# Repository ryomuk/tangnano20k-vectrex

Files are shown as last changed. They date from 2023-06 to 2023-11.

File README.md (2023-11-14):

# tangnano20k-vectrex
Tang Nano 20K top level module for Dar's Vectrex

This document is written mostly in Japanese. If necessary, please use a translation service such as DeepL (I recommend this) or Google.

## 概要
- Vectrex by Dar (darfpga@aol.fr) http://darfpga.blogspot.fr をTang Nano 20Kで動作させるためのトップレベルモジュール，オシロスコープ用信号出力のためのDAC(MCP4911)用モジュール，および周辺回路の回路図です．
- とりあえず作ってみただけなので，動作は完全ではありませんし，デバッグ用のコード等も入っています．
- [SourceForge DarFPGA](https://sourceforge.net/projects/darfpga/files/Software%20VHDL/vectrex/)にあったDE10-lite用のソースを改変して作りました．
- オリジナルのパッケージのREADME.TXTにあるように，下記のことを理解した上でご使用下さい．
  - Educational use only
  - Do not redistribute synthetized file with roms
  - Do not redistribute roms whatever the form
  - Use at your own risk

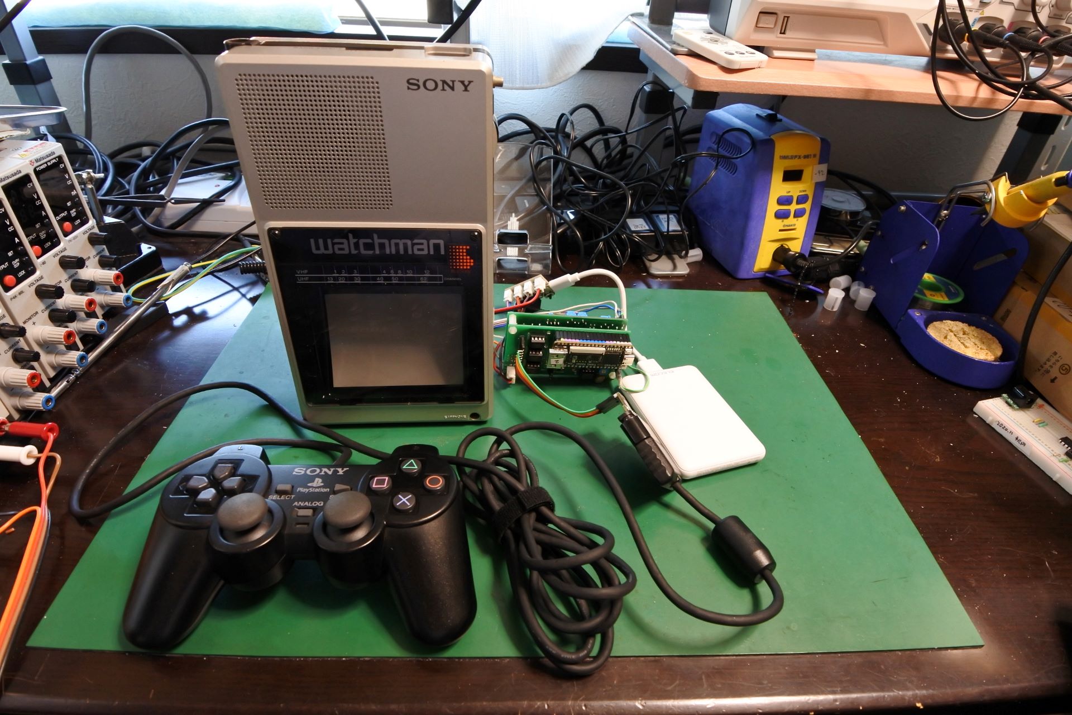
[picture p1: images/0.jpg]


### rev0.3 (まだ改善の余地があり，改版予定ありです．)
- VGA出力用のコードと回路は削除して，XYモニター(オシロスコープ)用の出力専用にしました．
- Sony WatchmanをXYモニタに改造するための回路を追加しました．この回路についての詳細は[https://github.com/ryomuk/XYamp](https://github.com/ryomuk/XYamp)を参照して下さい．

- コントローラーをアナログ対応にしました．TangNano20kゲームキットのコントローラは粗くてスティックの稼働範囲も狭いので，SONY純正のDualShock 2(SCPH-10010)をお薦めします．
- 基板を作ってみました．ブレッドボード版のノイズが改善されるかと思ったのですが改善されませんでした．

FPGA基板
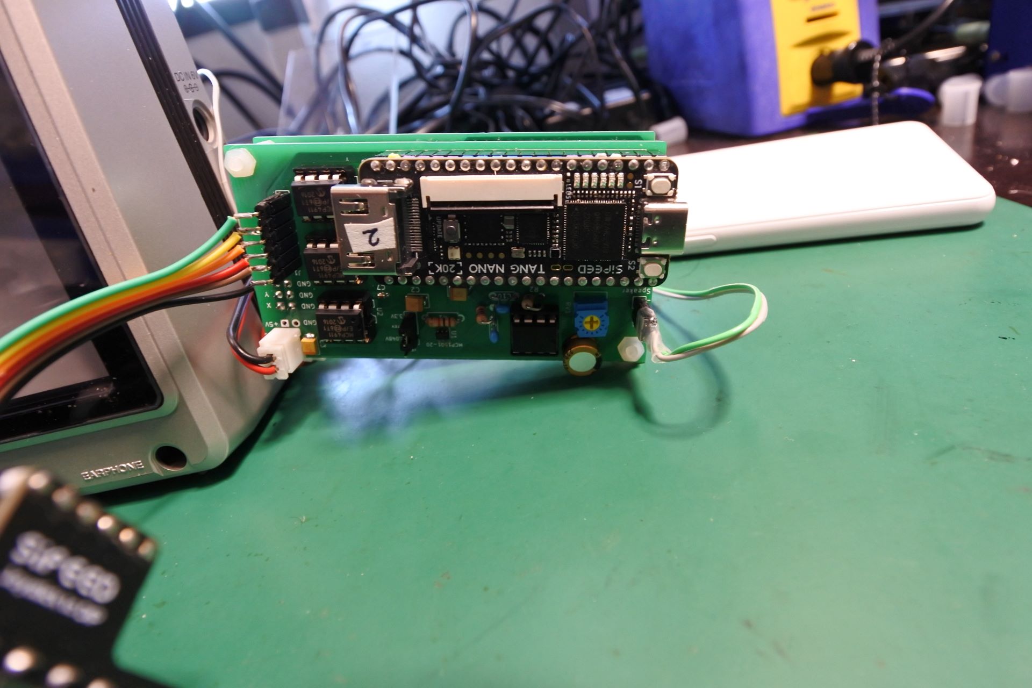
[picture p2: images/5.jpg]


XYアンプ基板
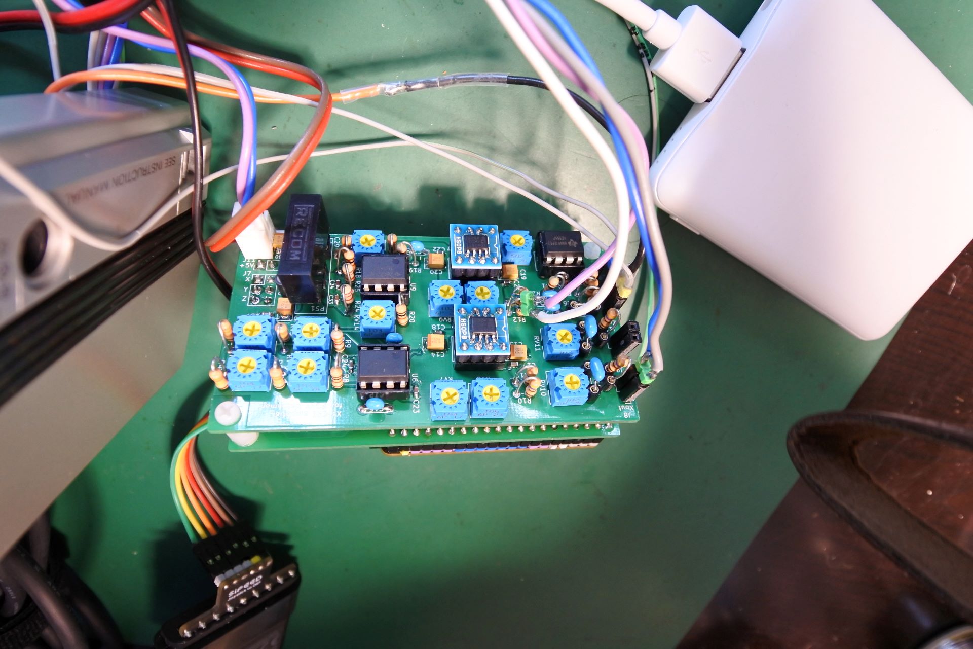
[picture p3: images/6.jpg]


電池ボックスに収納しようとしたけど入らない．
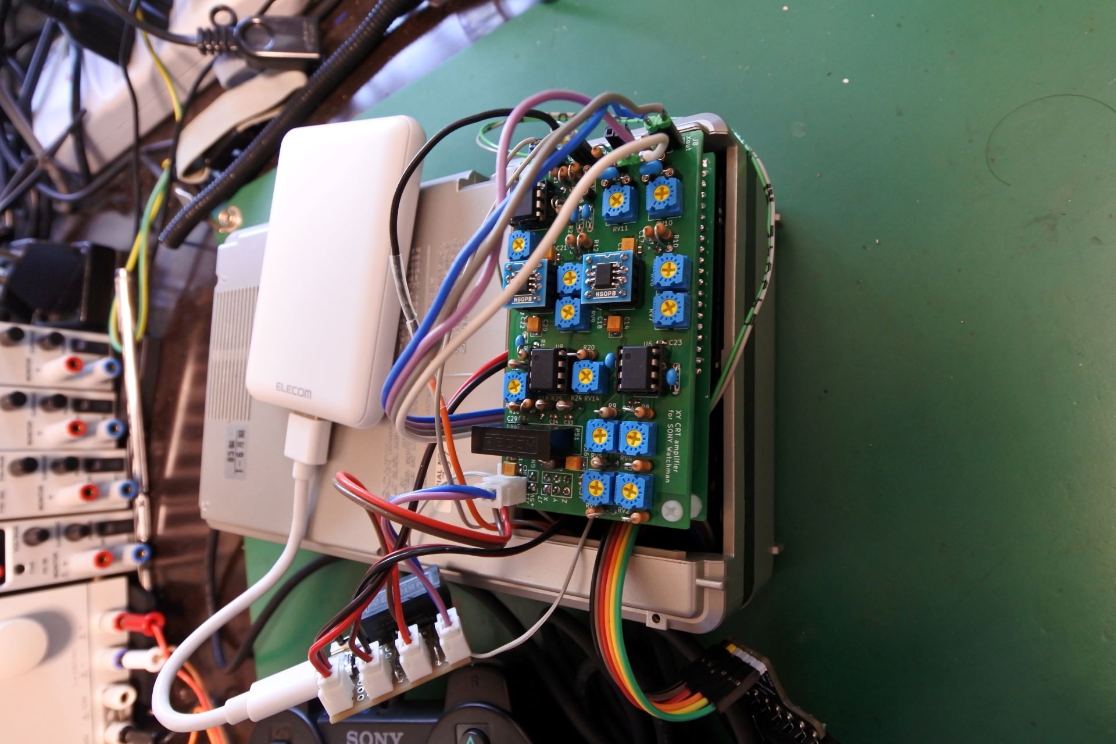
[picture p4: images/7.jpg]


## コンパイル方法

1. [SourceForge DarFPGA](https://sourceforge.net/projects/darfpga/files/Software%20VHDL/vectrex/)にある vhdl_vectrex_rev_0_2_2018_06_12.zip を展開する．
2. 展開してできた下記フォルダを，vectrex_project/src/に中身ごとコピーする．
```
cp -a rtl_dar rtl_jkent rtl_mikej rtl_pace vectrex_project/src/
```
3. ROMデータのvhdlファイルを用意して，romフォルダを作成してそこに置く．
```
mkdir vectrex_project/src/rom
cp vectrex_exec_prom.vhd vectrex_project/src/rom/ (必須)
cp vectrex_scramble_prom.vhd vectrex_project/src/rom/ (ゲームROMデータの例)
```
4. Gowin EDAでプロジェクト vectrex_project.gprj を開いてビルドする．
- "Project->Configuration->Dual-Purpose Pin->Use SSPI as regular IO"をチェックして下さい
- ROMデータのファイルは，プロジェクトに適宜追加・削除して下さい．

## ROMデータについて
- このレポジトリにはROMデータはありません．(romフォルダにあるのは空のテンプレートファイルです．)
- 必要なROMデータは何らかの方法で入手して，オリジナルのパッケージに含まれるREADME.TXTに従ってvhdlファイルを作成して下さい．
- データをVHDLに変換するスクリプトrom/rom2vhd.pl を使ってもいいかも．
- romの名前，サイズに応じて，rtl_dar/vectrex.vhdを適宜修正して下さい．

## その他
- このプロジェクトはあくまでFPGAを使う練習用の試みなので，バグ等があってもメンテナンスをする予定はありません．

# 動画
動作している様子です．

(https://www.youtube.com/watch?v=2sRUTAbVEdg)

## その他の画像
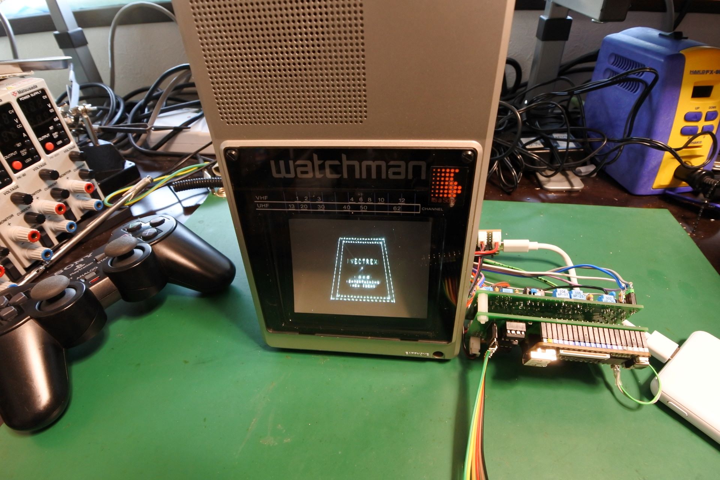
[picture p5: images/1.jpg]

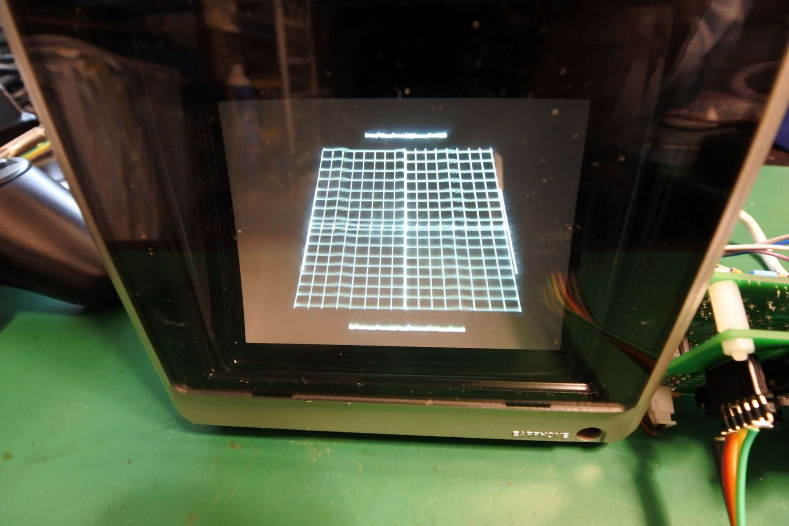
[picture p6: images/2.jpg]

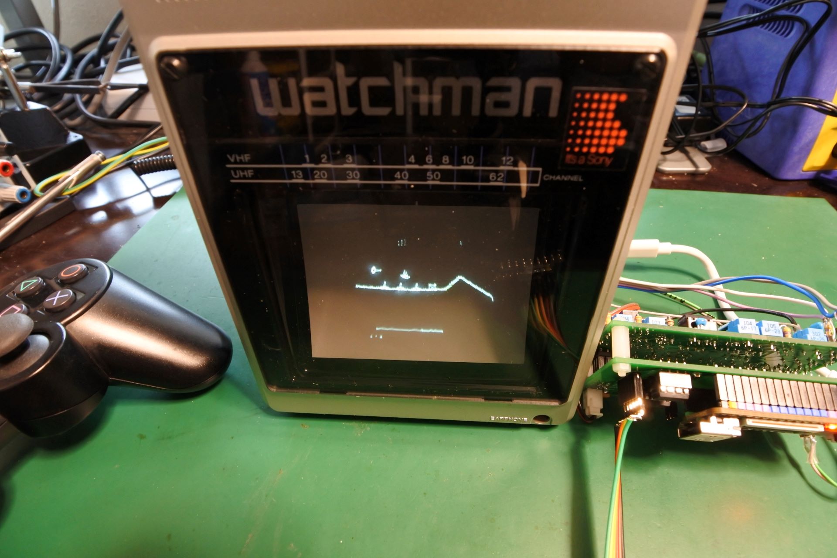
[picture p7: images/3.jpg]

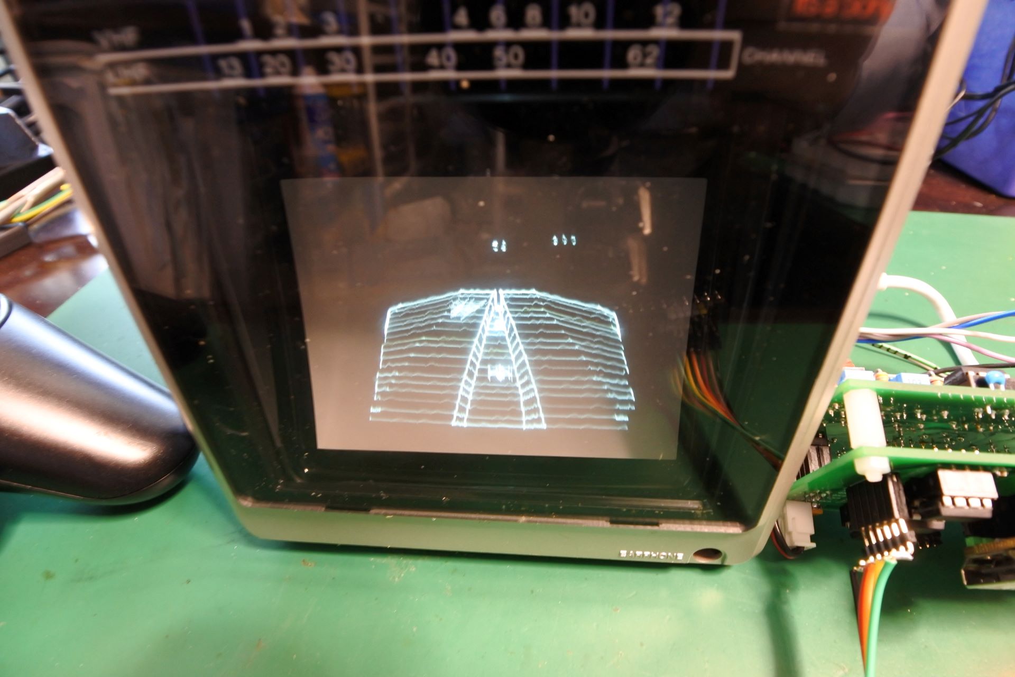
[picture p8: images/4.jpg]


## 更新履歴
- 2023/6/13: 初版公開
- 2023/6/13: 回路図にLPFが抜けていたので追加
- 2023/11/14: rev0.3公開．初版はold/rev0.1に移動．

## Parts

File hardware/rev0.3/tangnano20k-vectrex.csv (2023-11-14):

# | Reference | Qty | Value | Footprint | DNP
1 | C1, C2, C3, C13, C14, C19, C20, C30, C36 | 9 | 22u | 000_MyFootprint:CP_EIA-3528-15_AVX-H_Pad1.50x2.35mm_HandSolder
2 | C4, C5, C6, C7, C8, C9, C17, C18, C21, C22, C23, C24, C31, C37 | 14 | 0.1u | 000_MyFootprint:C_0603_1608Metric_Pad1.08x0.95mm_HandSolder
3 | C10, C27 | 2 | 0.01u | 000_MyFootprint:C_Disc_D4.3mm_W1.9mm_P5.00mm
4 | C11 | 1 | 0.047uF | 000_MyFootprint:C_Disc_D4.3mm_W1.9mm_P5.00mm
5 | C12 | 1 | 220u | 000_MyFootprint:CP_Radial_D4.0mm_P1.50mm
6 | C15, C16, C28 | 3 | 0.1u | 000_MyFootprint:C_Disc_D4.3mm_W1.9mm_P5.00mm
7 | C25, C26 | 2 | 1u | 000_MyFootprint:C_Disc_D4.7mm_W2.5mm_P5.00mm
8 | C29 | 1 | 2.2u | 000_MyFootprint:C_0603_1608Metric_Pad1.08x0.95mm_HandSolder
9 | C32 | 1 | 4700p | 000_MyFootprint:C_Disc_D4.3mm_W1.9mm_P5.00mm
10 | C33, C34 | 2 | 1u | 000_MyFootprint:C_0603_1608Metric_Pad1.08x0.95mm_HandSolder
11 | C35 | 1 | 0.068u | 000_MyFootprint:C_Disc_D4.3mm_W1.9mm_P5.00mm
12 | D1 | 1 | 1N4148 | 000_MyFootprint:D_DO-35_SOD27_P2.54mm_Vertical_AnodeUp
13 | FB1 | 1 | FerriteBead | 000_MyFootprint:R_Axial_DIN0207_L6.3mm_D2.5mm_P2.54mm_Vertical
14 | H1, H2, H3, H4 | 4 | MountingHole | 000_MyFootprint:MountingHole_3mm
15 | J1 | 1 | Joystick | 000_MyFootprint:PinSocket_1x06_P2.54mm_Vertical
16 | J2, J3 | 2 | TangNano20K | 000_MyFootprint:PinSocket_1x20_P2.54mm_Vertical
17 | J4, J11, J12 | 3 | 5V | 000_MyFootprint:PinHeader_1x02_P2.54mm_Vertical
18 | J5 | 1 | Vref | 000_MyFootprint:PinHeader_1x03_P2.54mm_Vertical
19 | J6, J7 | 2 | Conn_02x03_Odd_Even | 000_MyFootprint:PinHeader_2x03_P2.54mm_Vertical
20 | J8 | 1 | Xout | 000_MyFootprint:PinHeader_1x02_P2.54mm_Vertical
21 | J9 | 1 | Yout | 000_MyFootprint:PinHeader_1x02_P2.54mm_Vertical
22 | J10 | 1 | -5V | 000_MyFootprint:PinHeader_1x02_P2.54mm_Vertical
23 | J13 | 1 | flyback | 000_MyFootprint:PinHeader_1x02_P2.54mm_Vertical
24 | J14 | 1 | Zout | 000_MyFootprint:PinHeader_1x02_P2.54mm_Vertical
25 | LS1 | 1 | Speaker | 000_MyFootprint:PinHeader_1x02_P2.54mm_Vertical
26 | PS1 | 1 | MAU109 | 000_MyFootprint:SIP-6_without_3pin_for_DCDC_MAU
27 | R1 | 1 | 1k | 000_MyFootprint:R_Axial_DIN0207_L6.3mm_D2.5mm_P7.62mm_Horizontal
28 | R2, R9, R21 | 3 | 3.3k | 000_MyFootprint:R_Axial_DIN0207_L6.3mm_D2.5mm_P2.54mm_Vertical
29 | R3 | 1 | 10 | 000_MyFootprint:R_Axial_DIN0207_L6.3mm_D2.5mm_P2.54mm_Vertical
30 | R4, R5, R6, R7, R16, R17 | 6 | 330k | 000_MyFootprint:R_Axial_DIN0207_L6.3mm_D2.5mm_P2.54mm_Vertical
31 | R8, R18, R20, R23, R26 | 5 | 1k | 000_MyFootprint:R_Axial_DIN0207_L6.3mm_D2.5mm_P2.54mm_Vertical
32 | R10, R11, R12, R13, R14, R15 | 6 | 4.7 | 000_MyFootprint:R_Axial_DIN0207_L6.3mm_D2.5mm_P2.54mm_Vertical
33 | R19, R22 | 2 | 10k | 000_MyFootprint:R_Axial_DIN0207_L6.3mm_D2.5mm_P2.54mm_Vertical
34 | R24, R25 | 2 | 2.2k | 000_MyFootprint:R_Axial_DIN0207_L6.3mm_D2.5mm_P2.54mm_Vertical
35 | RV1, RV4, RV5, RV14 | 4 | 10k | 000_MyFootprint:Potentiometer_TOCOS_GF063
36 | RV2, RV3, RV7, RV12 | 4 | 100k | 000_MyFootprint:Potentiometer_TOCOS_GF063
37 | RV6, RV8 | 2 | 1M | 000_MyFootprint:Potentiometer_TOCOS_GF063
38 | RV9 | 1 | 1k | 000_MyFootprint:Potentiometer_TOCOS_GF063
39 | RV10, RV11 | 2 | 3k | 000_MyFootprint:Potentiometer_TOCOS_GF063
40 | RV13 | 1 | 5k | 000_MyFootprint:Potentiometer_TOCOS_GF063
41 | U1 | 1 | MCP1501-20 | Package_TO_SOT_SMD:SOT-23-6
42 | U2, U3, U4 | 3 | MCP4911 | 000_MyFootprint:DIP-8_W7.62mm
43 | U5 | 1 | LM386 | 000_MyFootprint:DIP-8_W7.62mm
44 | U6, U9 | 2 | TL072 | 000_MyFootprint:DIP-8_W7.62mm
45 | U7, U8 | 2 | AD8397 | 000_MyFootprint:DIP-8_W7.62mm_with_SOP8_with_heatpadhole
46 | U10 | 1 | NE555 | 000_MyFootprint:DIP-8_W7.62mm

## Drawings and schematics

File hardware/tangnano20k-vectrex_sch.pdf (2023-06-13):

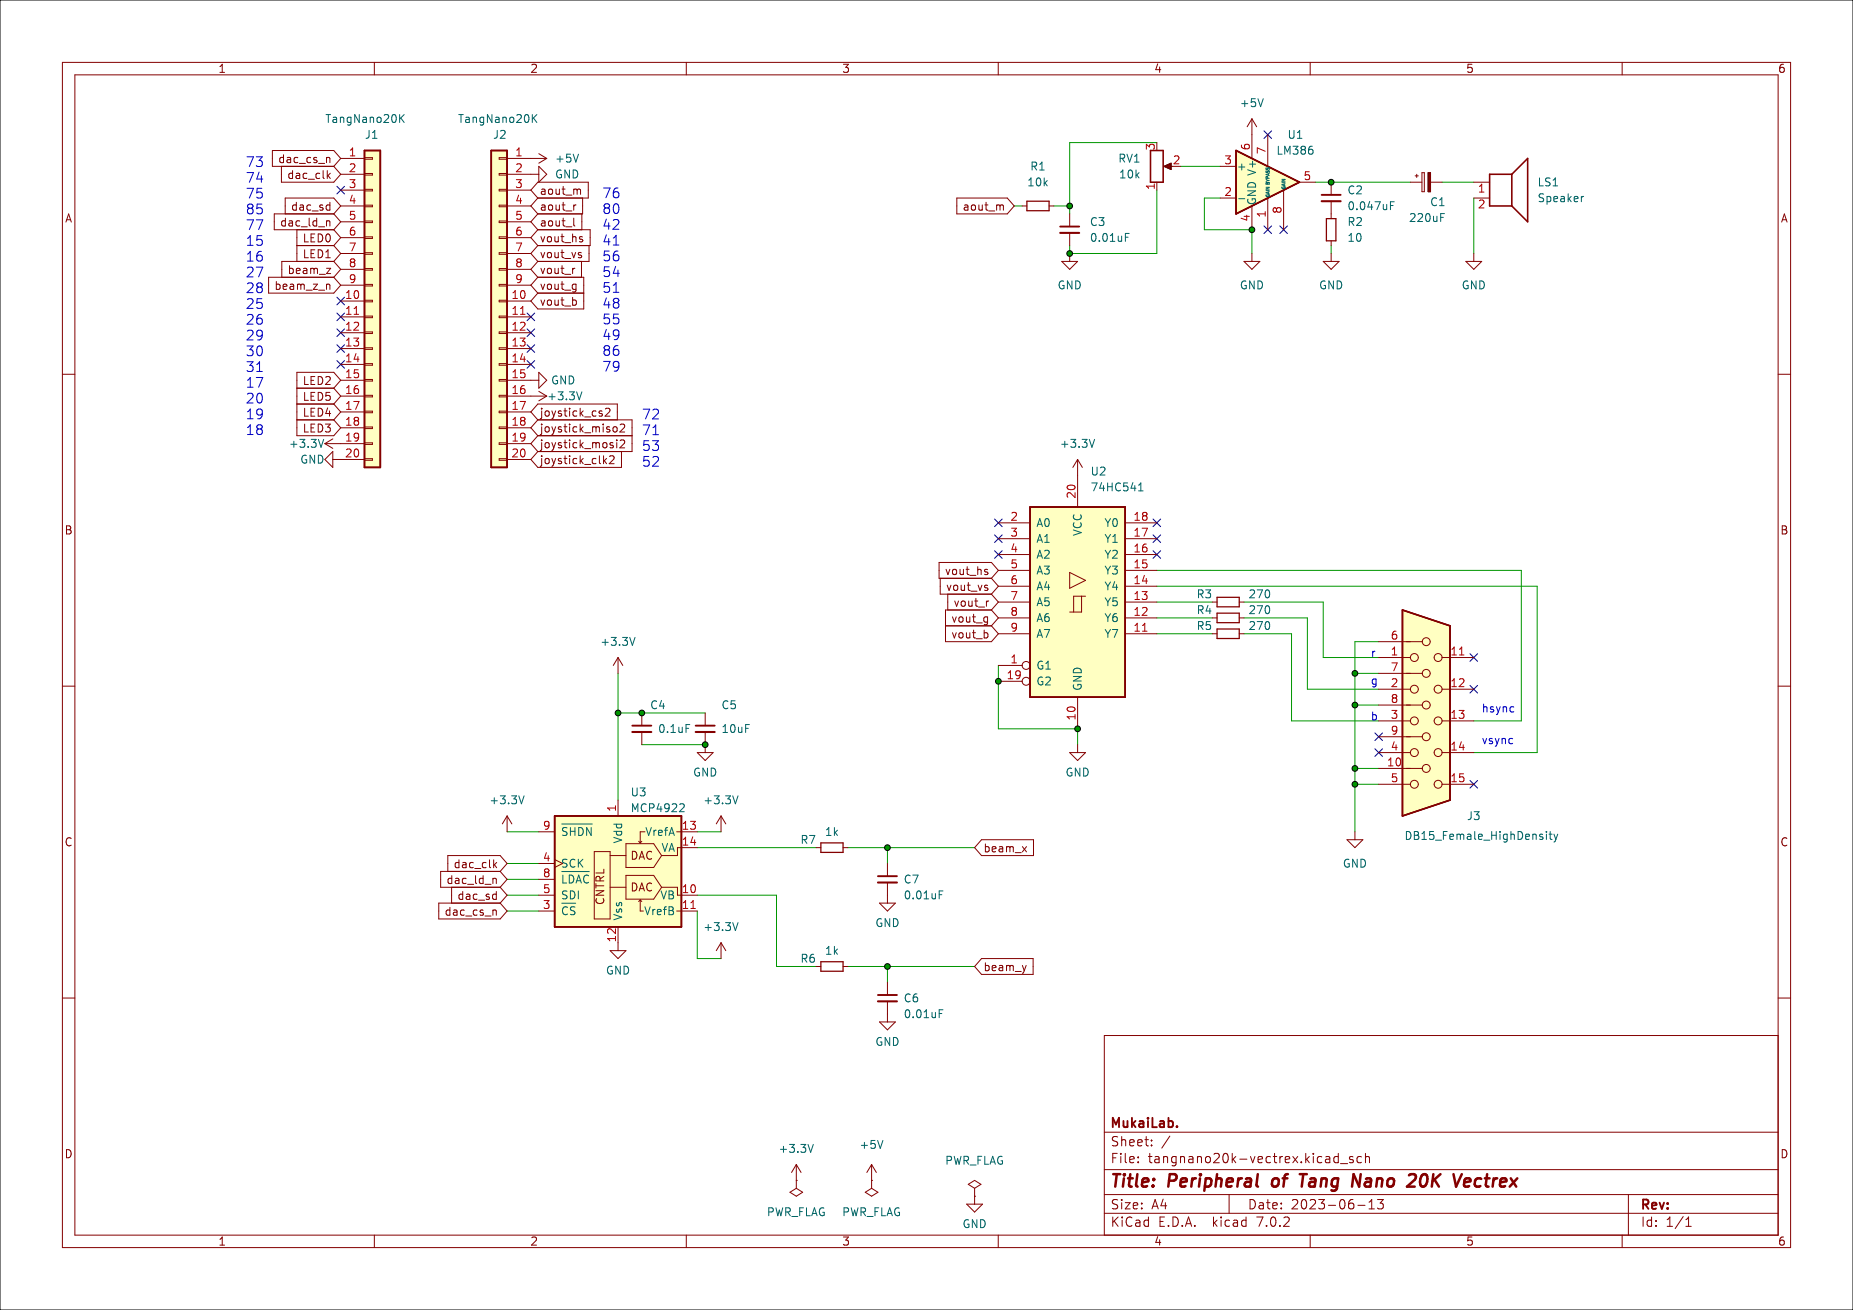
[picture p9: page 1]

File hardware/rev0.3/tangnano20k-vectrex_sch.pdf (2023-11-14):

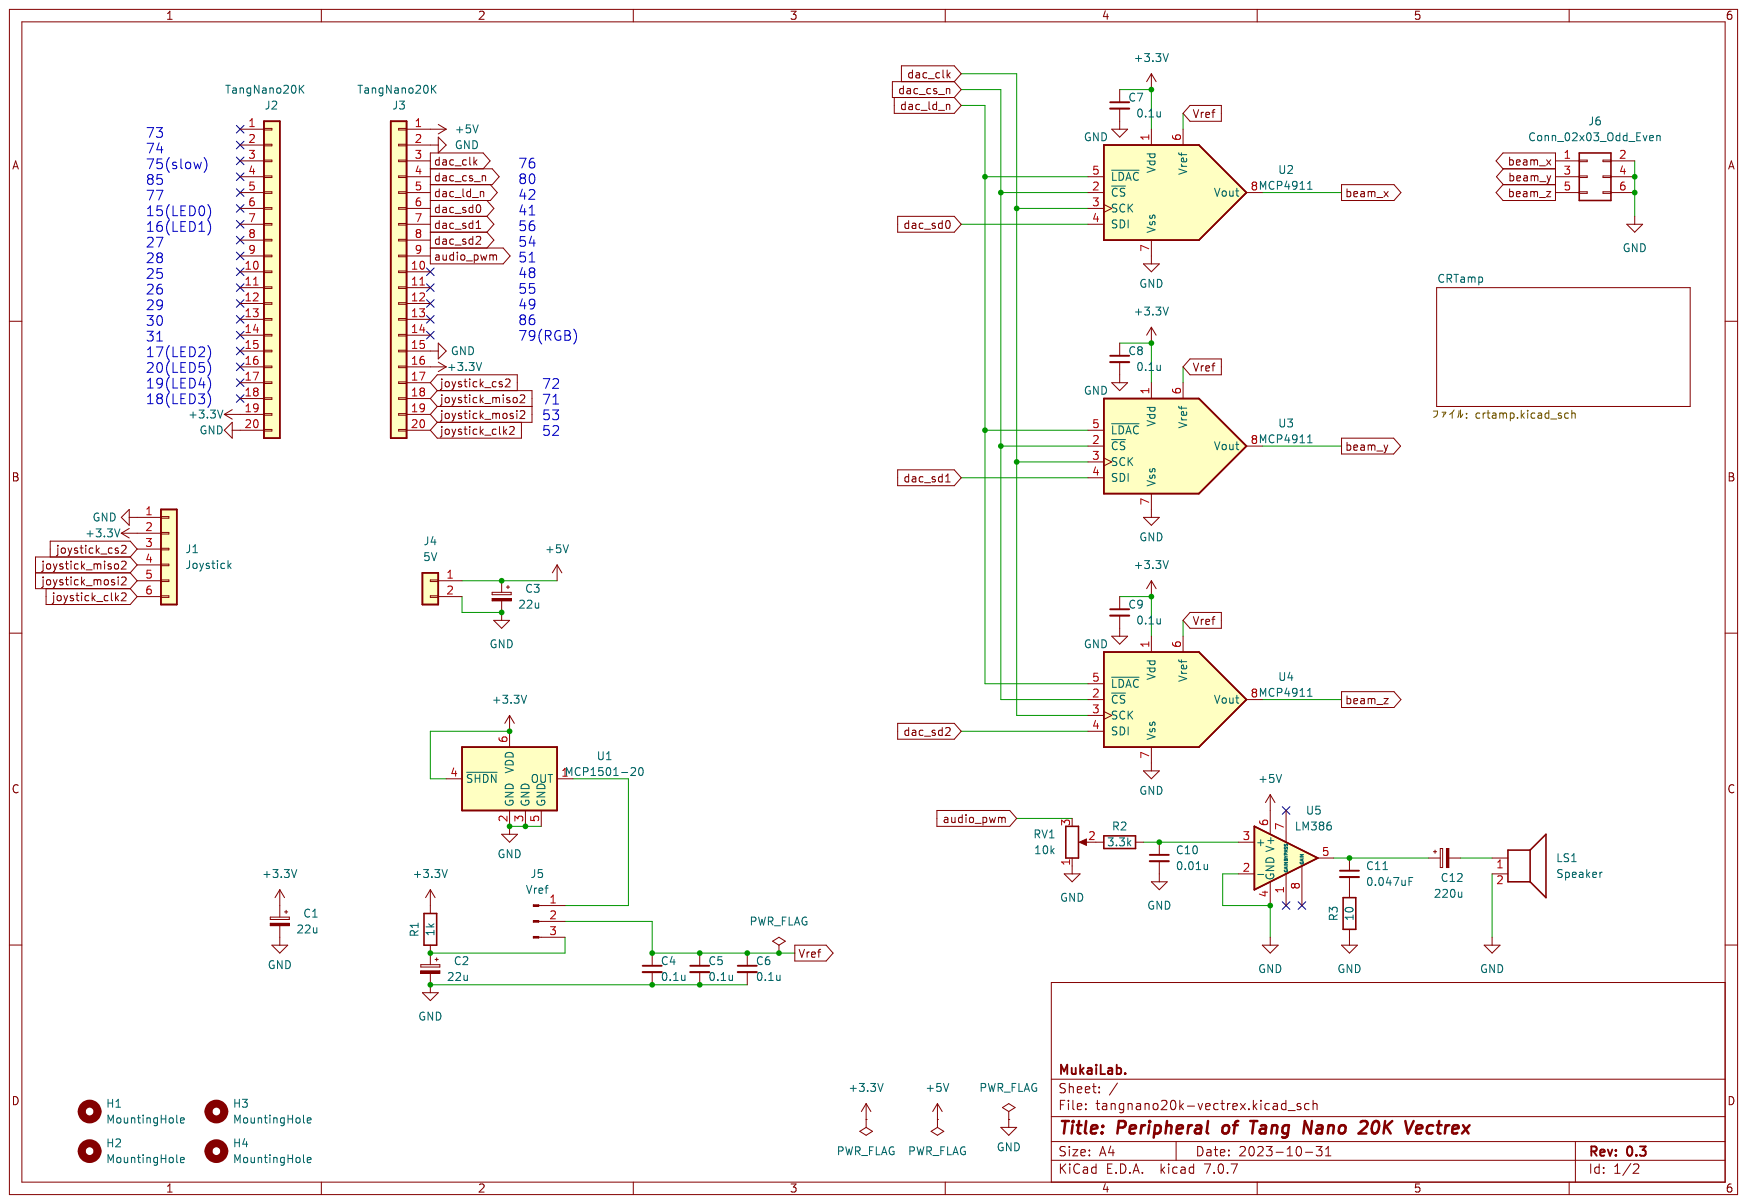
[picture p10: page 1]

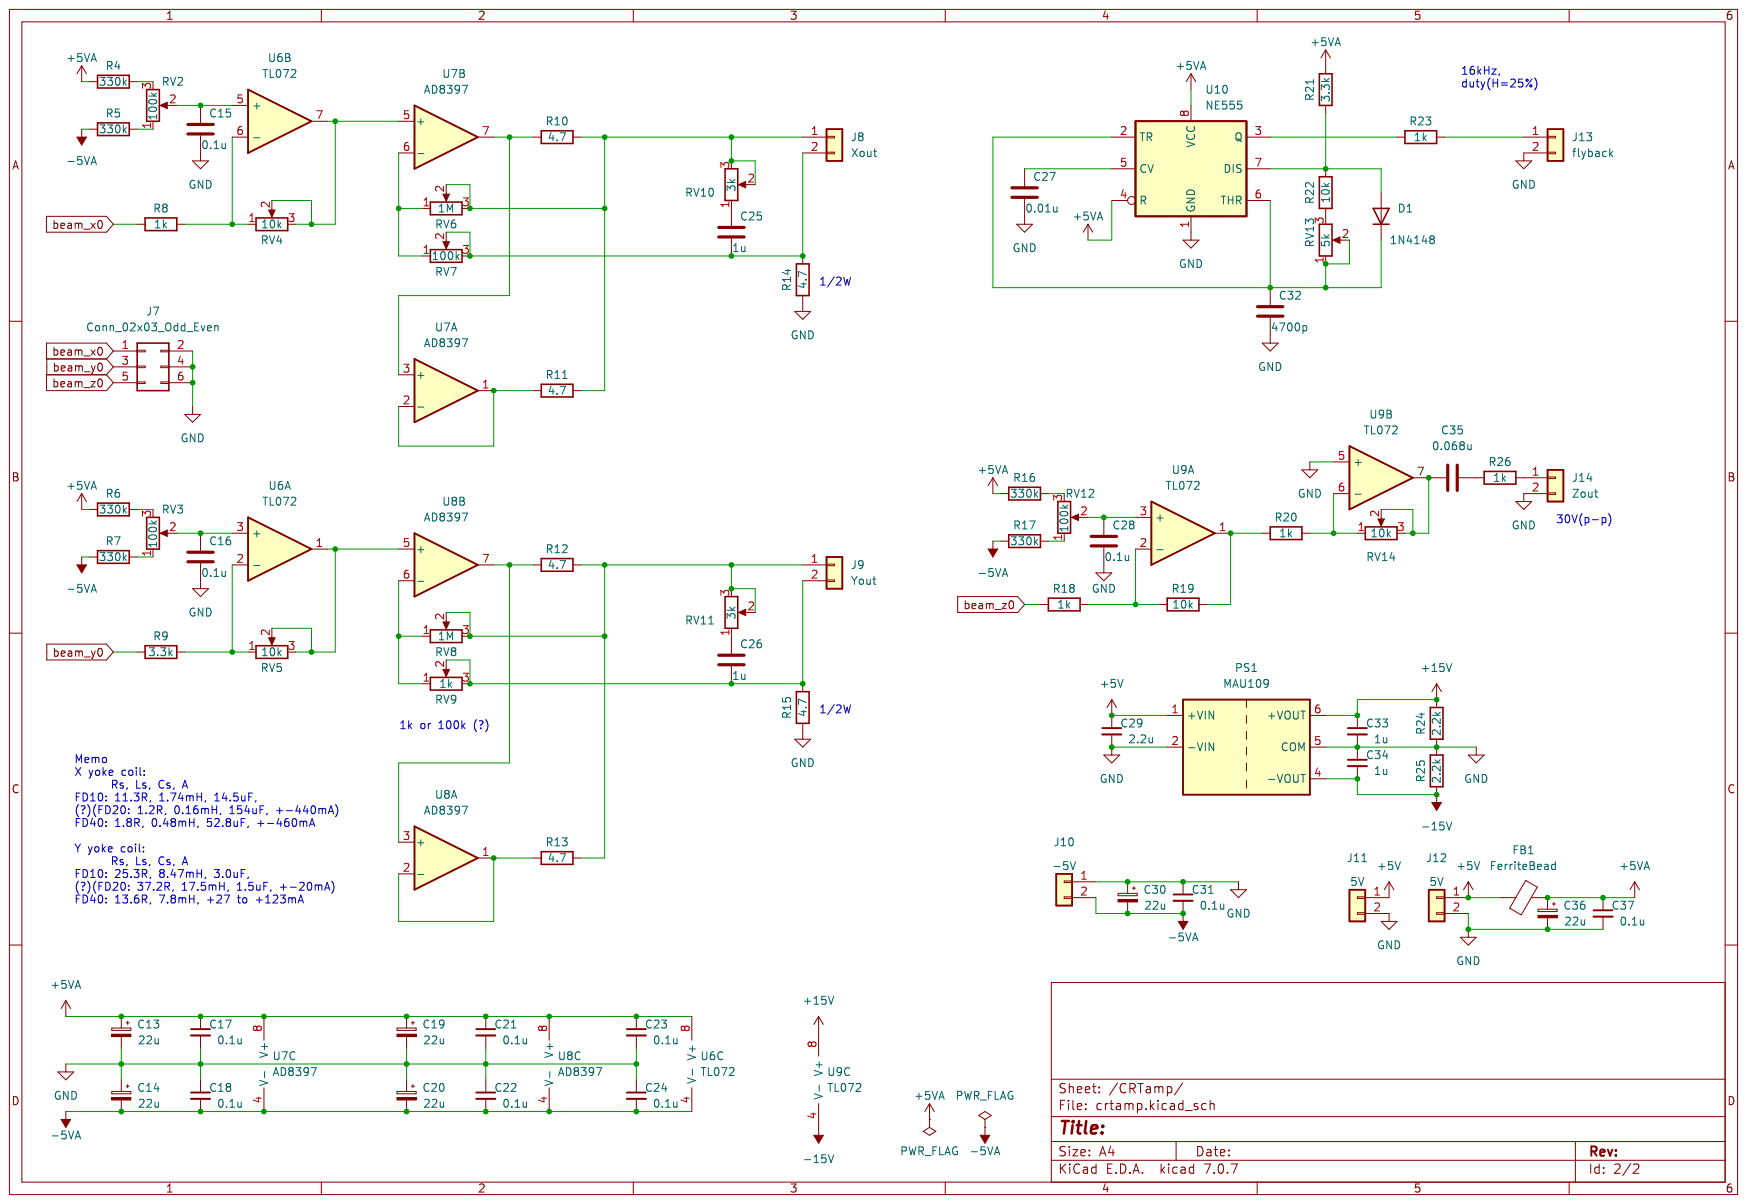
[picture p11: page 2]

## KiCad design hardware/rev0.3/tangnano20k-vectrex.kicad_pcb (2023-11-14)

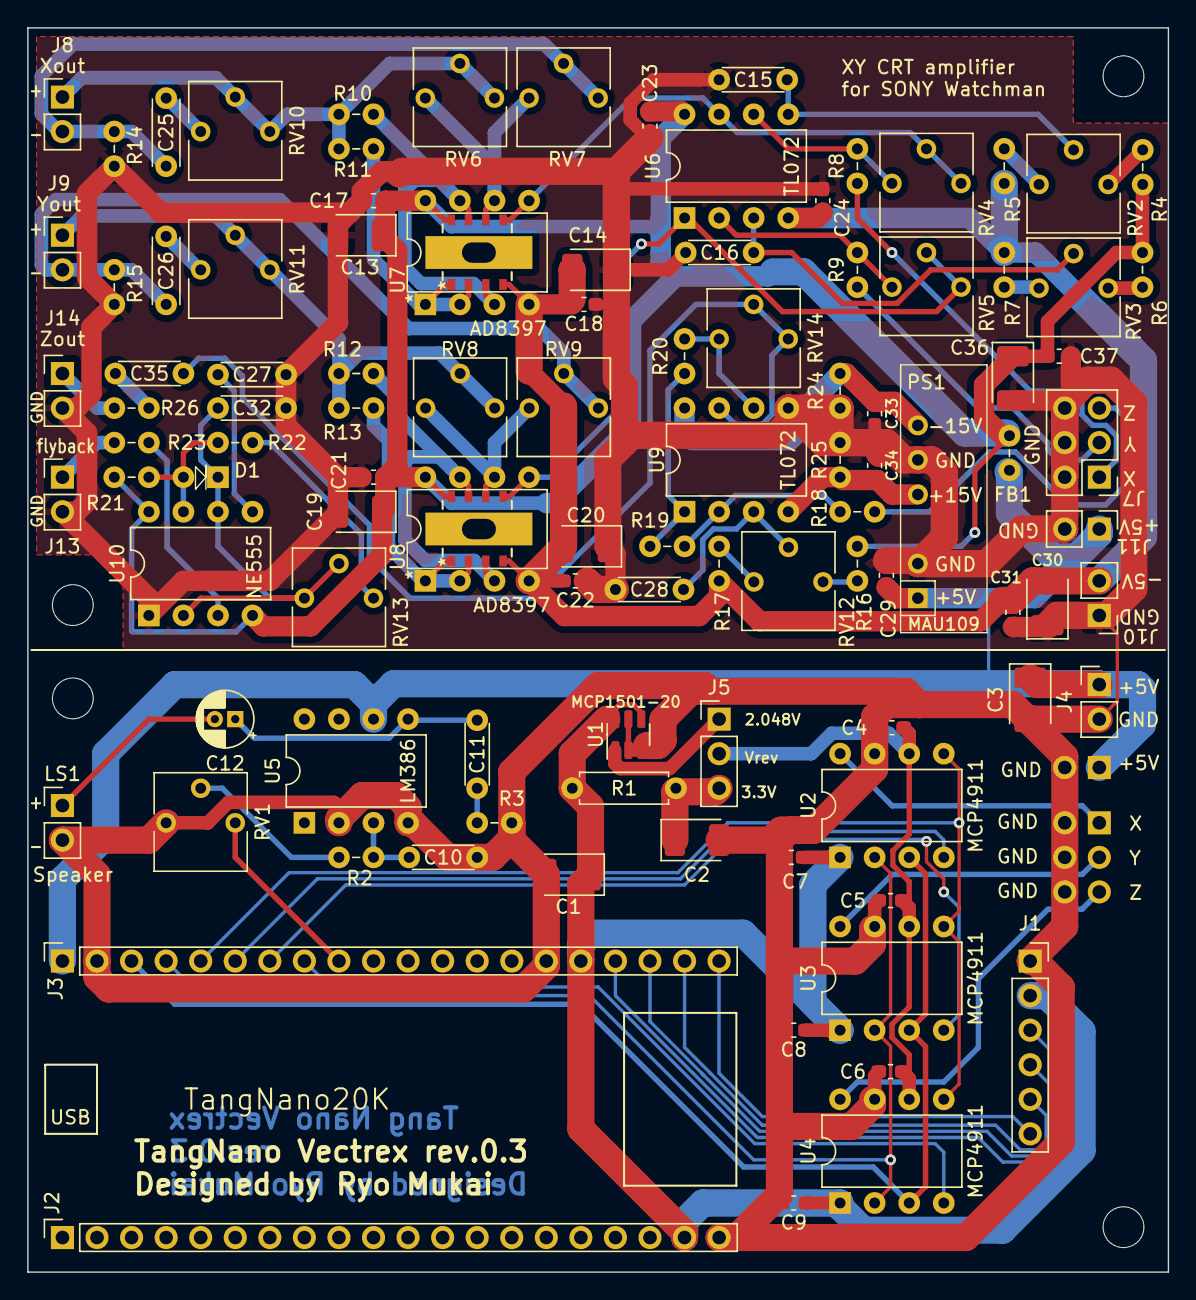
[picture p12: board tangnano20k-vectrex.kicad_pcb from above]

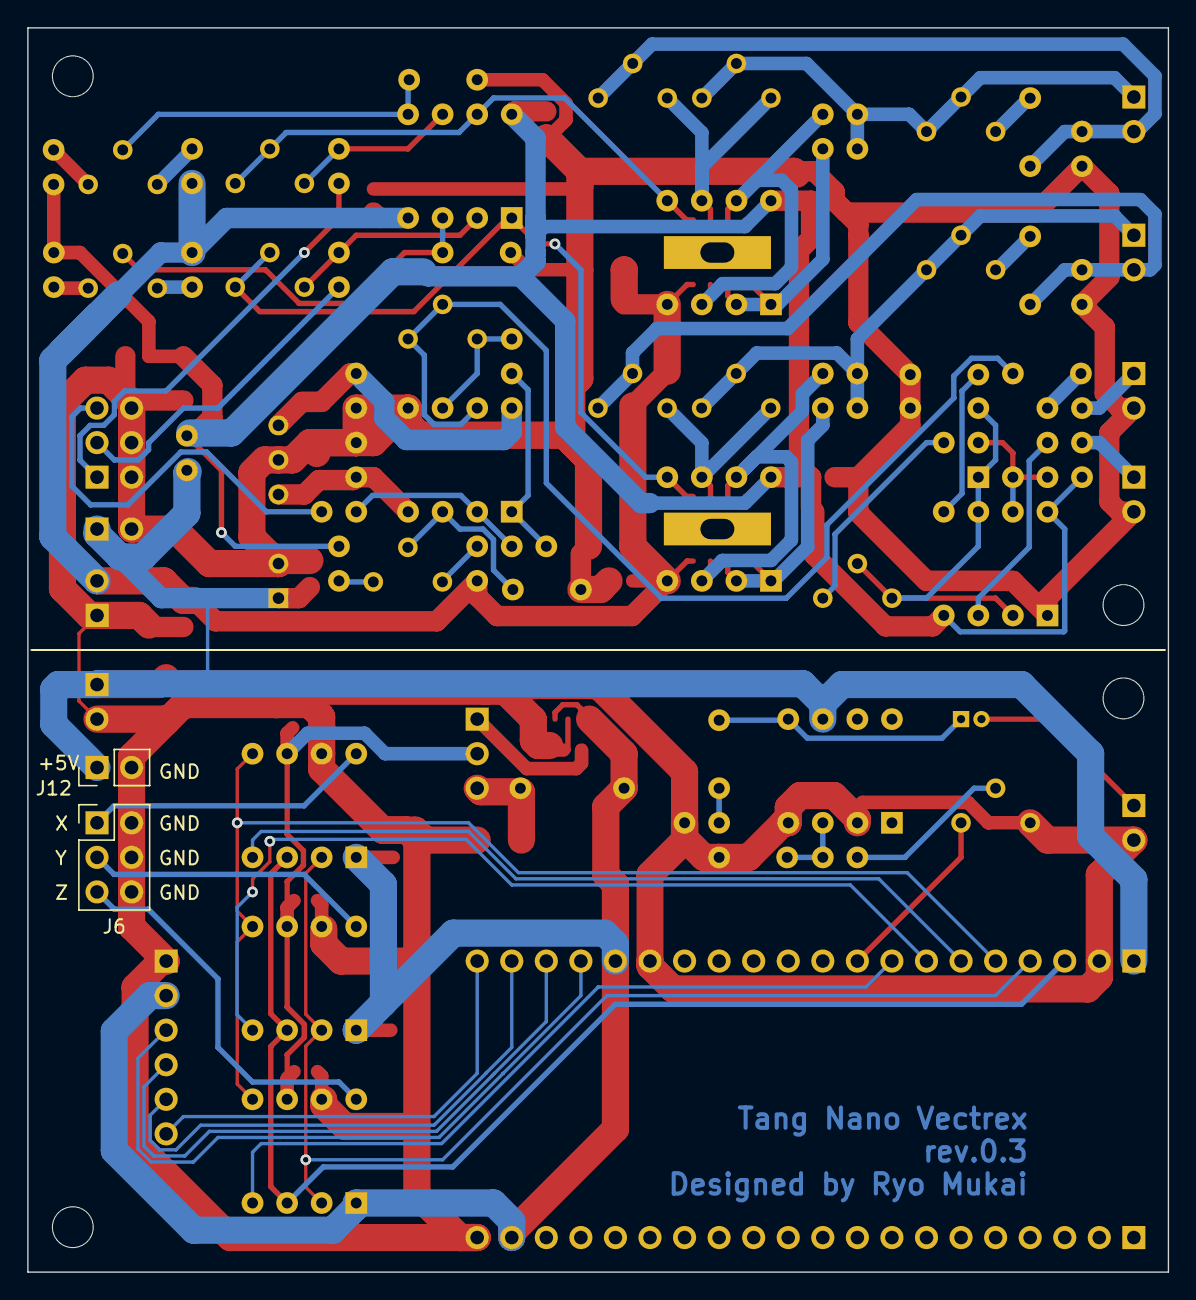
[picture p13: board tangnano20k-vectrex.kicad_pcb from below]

Board: 2 copper layers, 83.8 x 91.4 mm, 109 parts (2 on the bottom side), 69 nets.

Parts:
C1, C2, C3, C13, C14, C19, C20, C30, C36: 22u; CP_EIA-3528-15_AVX-H_Pad1.50x2.35mm_HandSolder
C4, C5, C6, C7, C8, C9, C17, C18, C21, C22, C23, C24, C31, C37: 0.1u; C_0603_1608Metric_Pad1.08x0.95mm_HandSolder
C10, C27: 0.01u; C_Disc_D4.3mm_W1.9mm_P5.00mm
C11: 0.047uF; C_Disc_D4.3mm_W1.9mm_P5.00mm
C12: 220u; CP_Radial_D4.0mm_P1.50mm
C15, C16, C28: 0.1u; C_Disc_D4.3mm_W1.9mm_P5.00mm
C25, C26: 1u; C_Disc_D4.7mm_W2.5mm_P5.00mm
C29: 2.2u; C_0603_1608Metric_Pad1.08x0.95mm_HandSolder
C32: 4700p; C_Disc_D4.3mm_W1.9mm_P5.00mm
C33, C34: 1u; C_0603_1608Metric_Pad1.08x0.95mm_HandSolder
C35: 0.068u; C_Disc_D4.3mm_W1.9mm_P5.00mm
D1: 1N4148; D_DO-35_SOD27_P2.54mm_Vertical_AnodeUp
FB1: FerriteBead; R_Axial_DIN0207_L6.3mm_D2.5mm_P2.54mm_Vertical
H1, H2, H3, H4: MountingHole; MountingHole_3mm
J1: Joystick; PinSocket_1x06_P2.54mm_Vertical
J2, J3: TangNano20K; PinSocket_1x20_P2.54mm_Vertical
J4, J11, J12: 5V; PinHeader_1x02_P2.54mm_Vertical
J5: Vref; PinHeader_1x03_P2.54mm_Vertical
J6, J7: Conn_02x03_Odd_Even; PinHeader_2x03_P2.54mm_Vertical
J8: Xout; PinHeader_1x02_P2.54mm_Vertical
J9: Yout; PinHeader_1x02_P2.54mm_Vertical
J10: -5V; PinHeader_1x02_P2.54mm_Vertical
J13: flyback; PinHeader_1x02_P2.54mm_Vertical
J14: Zout; PinHeader_1x02_P2.54mm_Vertical
LS1: Speaker; PinHeader_1x02_P2.54mm_Vertical
PS1: MAU109; SIP-6_without_3pin_for_DCDC_MAU
R1: 1k; R_Axial_DIN0207_L6.3mm_D2.5mm_P7.62mm_Horizontal
R2, R19, R22: 10k; R_Axial_DIN0207_L6.3mm_D2.5mm_P2.54mm_Vertical
R3: 10; R_Axial_DIN0207_L6.3mm_D2.5mm_P2.54mm_Vertical
R4, R5, R6, R7, R16, R17: 330k; R_Axial_DIN0207_L6.3mm_D2.5mm_P2.54mm_Vertical
R8, R18, R20, R23, R26: 1k; R_Axial_DIN0207_L6.3mm_D2.5mm_P2.54mm_Vertical
R9, R21: 3.3k; R_Axial_DIN0207_L6.3mm_D2.5mm_P2.54mm_Vertical
R10, R11, R12, R13, R14, R15: 4.7; R_Axial_DIN0207_L6.3mm_D2.5mm_P2.54mm_Vertical
R24, R25: 2.2k; R_Axial_DIN0207_L6.3mm_D2.5mm_P2.54mm_Vertical
RV1, RV4, RV5, RV14: 10k; Potentiometer_TOCOS_GF063
RV2, RV3, RV7, RV12: 100k; Potentiometer_TOCOS_GF063
RV6, RV8: 1M; Potentiometer_TOCOS_GF063
RV9: 1k; Potentiometer_TOCOS_GF063
RV10, RV11: 3k; Potentiometer_TOCOS_GF063
RV13: 5k; Potentiometer_TOCOS_GF063
U1: MCP1501-20; SOT-23-6
U2, U3, U4: MCP4911; DIP-8_W7.62mm
U5: LM386; DIP-8_W7.62mm
U6, U9: TL072; DIP-8_W7.62mm
U7, U8: AD8397; DIP-8_W7.62mm_with_SOP8_with_heatpadhole
U10: NE555; DIP-8_W7.62mm

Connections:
+3.3V: C1.1, C7.1, C8.1, C9.1, J1.2, J2.19, J3.16, R1.2, U1.4 (~SHDN), U1.6 (VDD), U2.1 (Vdd), U3.1 (Vdd), U4.1 (Vdd)
+5V: C3.1, C29.1, FB1.1, J3.1, J4.1, J11.1, J12.1, PS1.1 (+VIN), U5.6 (V+)
+5VA: C13.1, C17.1, C19.1, C21.1, C23.1, C36.1, C37.1, FB1.2, R4.1, R6.1, R16.1, R21.2, U6.8 (V+), U7.8 (V+), U8.8 (V+), U10.4 (R), U10.8 (VCC)
+15V: C33.1, PS1.6 (+VOUT), R24.2, U9.8 (V+)
-5VA: C14.2, C18.2, C20.2, C22.2, C24.2, C30.2, C31.2, J10.2, R5.1, R7.1, R17.1, U6.4 (V-), U7.4 (V-), U8.4 (V-)
-15V: C34.2, PS1.4 (-VOUT), R25.1, U9.4 (V-)
GND: C1.2, C2.2, C3.2, C4.2, C5.2, C6.2, C7.2, C8.2, C9.2, C10.2, C13.2, C14.1, C15.2, C16.2, C17.2, C18.1, C19.2, C20.1, C21.2, C22.1, C23.2, C24.1, C27.2, C28.2, C29.2, C30.1, C31.1, C32.2, C33.2, C34.1, C36.2, C37.2, J1.1, J2.20, J3.2, J3.15, J4.2, J6.2, J6.4, J6.6, J7.2, J7.4, J7.6, J10.1, J11.2, J12.2, J13.2, J14.2, LS1.2, PS1.2 (-VIN), PS1.5 (COM), R3.1, R14.1, R15.1, R24.1, R25.2, RV1.1, U1.2 (GND), U1.3 (GND), U1.5 (GND), U2.7 (Vss), U3.7 (Vss), U4.7 (Vss), U5.2 (-), U5.4 (GND), U9.5 (+), U10.1 (GND)
unnamed: C11.1, C12.1, U5.5
unnamed: C11.2, R3.2
unnamed: C12.2, LS1.1
unnamed: C25.1, RV10.1
unnamed: C26.1, RV11.1
unnamed: C35.1, RV14.2, RV14.3, U9.7
unnamed: C35.2, R26.1
unnamed: D1.2 (A), R21.1, R22.2, U10.7 (DIS)
unnamed: C32.1, D1.1 (K), RV13.1, RV13.2, U10.2 (TR), U10.6 (THR)
unnamed: J5.1, U1.1 (OUT)
unnamed: C2.1, J5.3, R1.1
unnamed: J8.1, R10.2, R11.2, RV6.2, RV6.3, RV10.2, RV10.3
unnamed: C25.2, J8.2, R14.2, RV7.2, RV7.3
unnamed: J9.1, R12.2, R13.2, RV8.2, RV8.3, RV11.2, RV11.3
unnamed: C26.2, J9.2, R15.2, RV9.2, RV9.3
unnamed: J13.1, R23.2
unnamed: J14.1, R26.2
unnamed: R2.1, RV1.2
unnamed: R4.2, RV2.3
unnamed: R5.2, RV2.1
unnamed: R6.2, RV3.3
unnamed: R7.2, RV3.1
unnamed: R16.2, RV12.3
unnamed: R17.2, RV12.1
unnamed: R19.2, R20.1, U9.1
unnamed: R22.1, RV13.3
unnamed: C10.1, R2.2, U5.3 (+)
unnamed: C16.1, RV3.2, U6.3 (+)
unnamed: R9.2, RV5.1, U6.2 (-)
unnamed: C15.1, RV2.2, U6.5 (+)
unnamed: R8.2, RV4.1, U6.6 (-)
unnamed: R10.1, U7.3 (+), U7.7
unnamed: R11.1, U7.1, U7.2 (-)
unnamed: RV4.2, RV4.3, U6.7, U7.5 (+)
unnamed: RV6.1, RV7.1, U7.6 (-)
unnamed: R12.1, U8.3 (+), U8.7
unnamed: R13.1, U8.1, U8.2 (-)
unnamed: RV5.2, RV5.3, U6.1, U8.5 (+)
unnamed: RV8.1, RV9.1, U8.6 (-)
unnamed: C28.1, RV12.2, U9.3 (+)
unnamed: R18.2, R19.1, U9.2 (-)
unnamed: R20.2, RV14.1, U9.6 (-)
unnamed: C27.1, U10.5 (CV)
unnamed: R23.1, U10.3 (Q)
Vref: C4.1, C5.1, C6.1, J5.2, U2.6 (Vref), U3.6 (Vref), U4.6 (Vref)
audio_pwm: J3.9, RV1.3
beam_x: J6.1, U2.8 (Vout)
beam_x0: J7.1, R8.1
beam_y: J6.3, U3.8 (Vout)
beam_y0: J7.3, R9.1
beam_z: J6.5, U4.8 (Vout)
beam_z0: J7.5, R18.1
dac_clk: J3.3, U2.3 (SCK), U3.3 (SCK), U4.3 (SCK)
dac_cs_n: J3.4, U2.2 (~CS), U3.2 (~CS), U4.2 (~CS)
dac_ld_n: J3.5, U2.5 (~LDAC), U3.5 (~LDAC), U4.5 (~LDAC)
dac_sd0: J3.6, U2.4 (SDI)
dac_sd1: J3.7, U3.4 (SDI)
dac_sd2: J3.8, U4.4 (SDI)
joystick_clk2: J1.6, J3.20
joystick_cs2: J1.3, J3.17
joystick_miso2: J1.4, J3.18
joystick_mosi2: J1.5, J3.19

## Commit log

2023-06-13 LPF added in schematics
2023-11-14 updated to rev0.3
    [crtamp.kicad_sch, power.kicad_sch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]
